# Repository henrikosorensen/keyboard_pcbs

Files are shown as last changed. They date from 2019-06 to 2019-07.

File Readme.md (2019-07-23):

GPLV2 licensed replacement keyboard PCBs.

# Omnikey 
Requires an Teensy++ 2.0 controller. - Firmware at https://github.com/qmk/qmk_firmware/tree/master/keyboards/omnikeyish

## Changelog

#### 1.3
* Nav cluster to Numpad cluster distance was off by 1/32 of an inch (0.7935mm). Meassurement confirmed on two original Omnikey PCBs and Plus rev3 plate. Not quite sure how I managed to assemble the first board.
* Rev1/3 Mounting holes got jumbled up in Schematic Reorganisation. Fixed now.

#### 1.1
* Teensy++ 2.0 uses pin D6 for an LED, so that interfers with the ROW5 assignment used on 1.0 boards. Moved ROW5 to pin E6

# AT101
Requires an Teensy 2.0 controller 

## Changelog

### 1.1
* Nav and numeric cluster distances to the alpha block were off by 1/32 inch.
* Big Arse Enter footprint updated, so stabiliser hole is large enough.

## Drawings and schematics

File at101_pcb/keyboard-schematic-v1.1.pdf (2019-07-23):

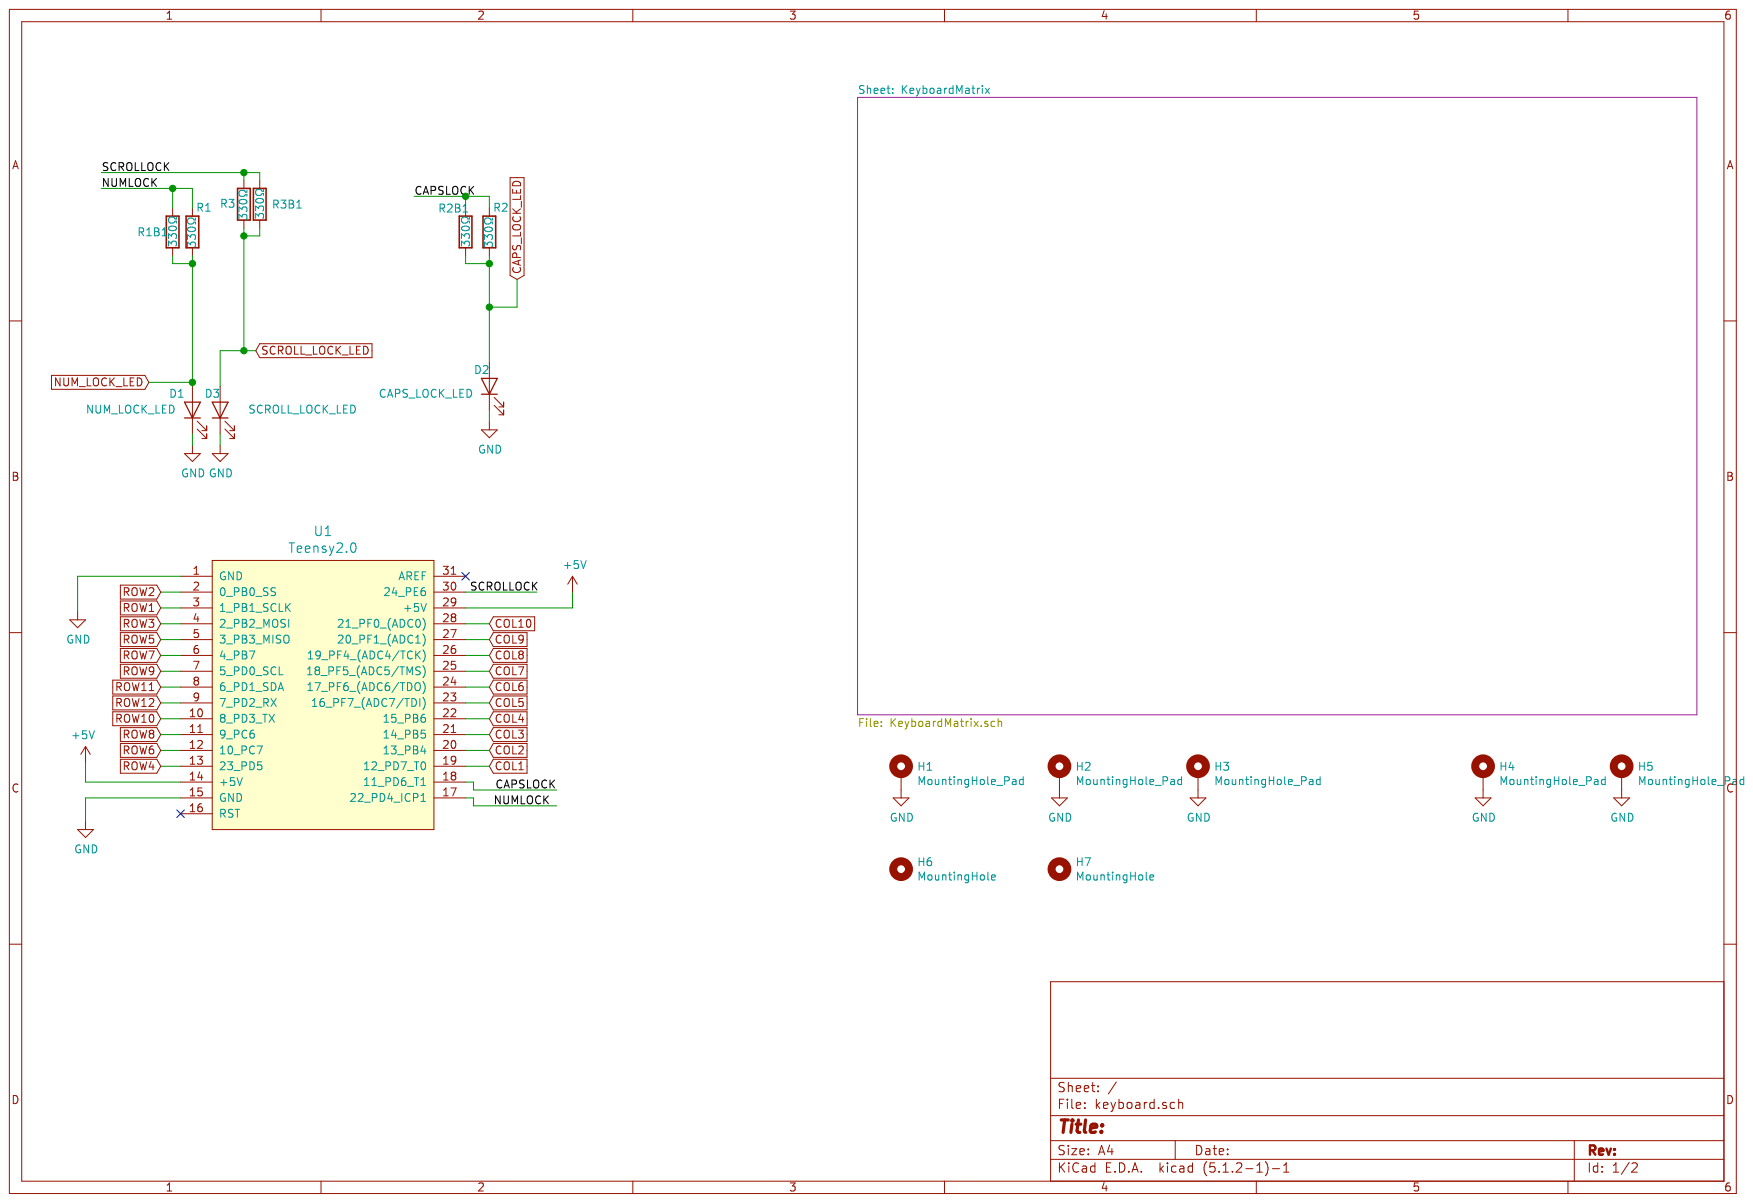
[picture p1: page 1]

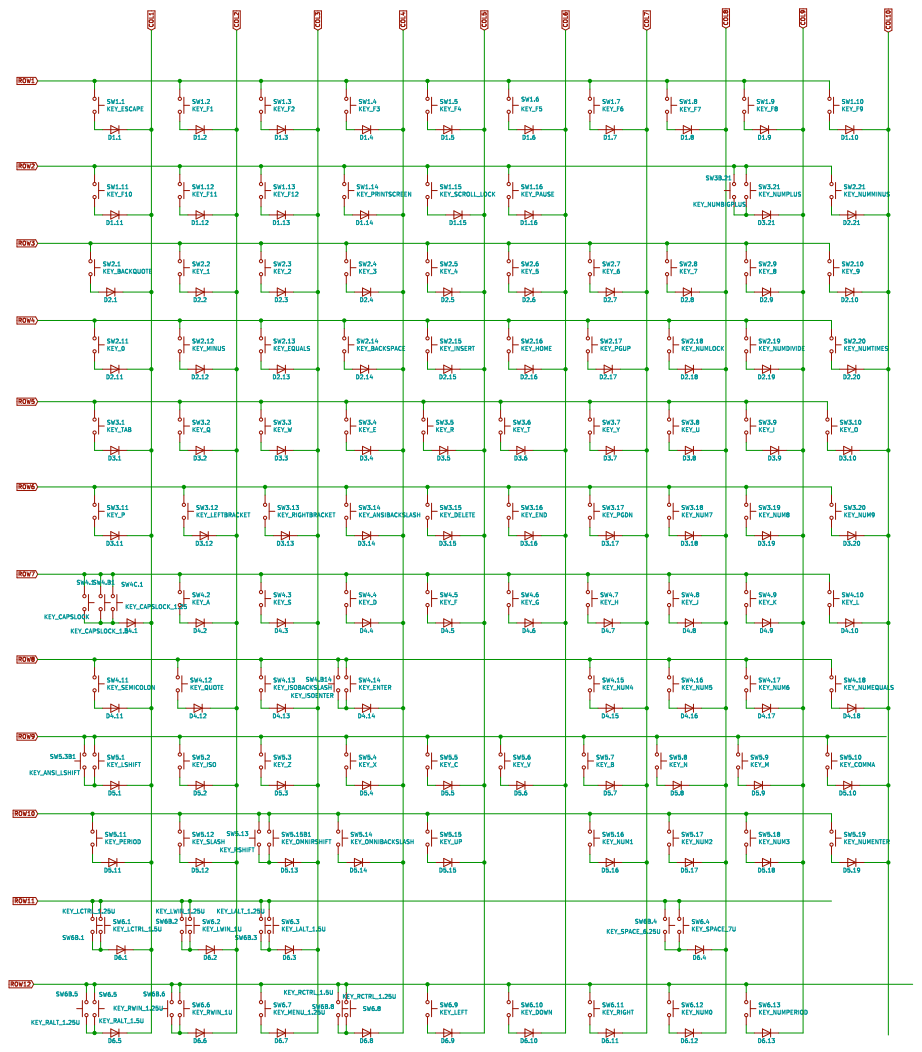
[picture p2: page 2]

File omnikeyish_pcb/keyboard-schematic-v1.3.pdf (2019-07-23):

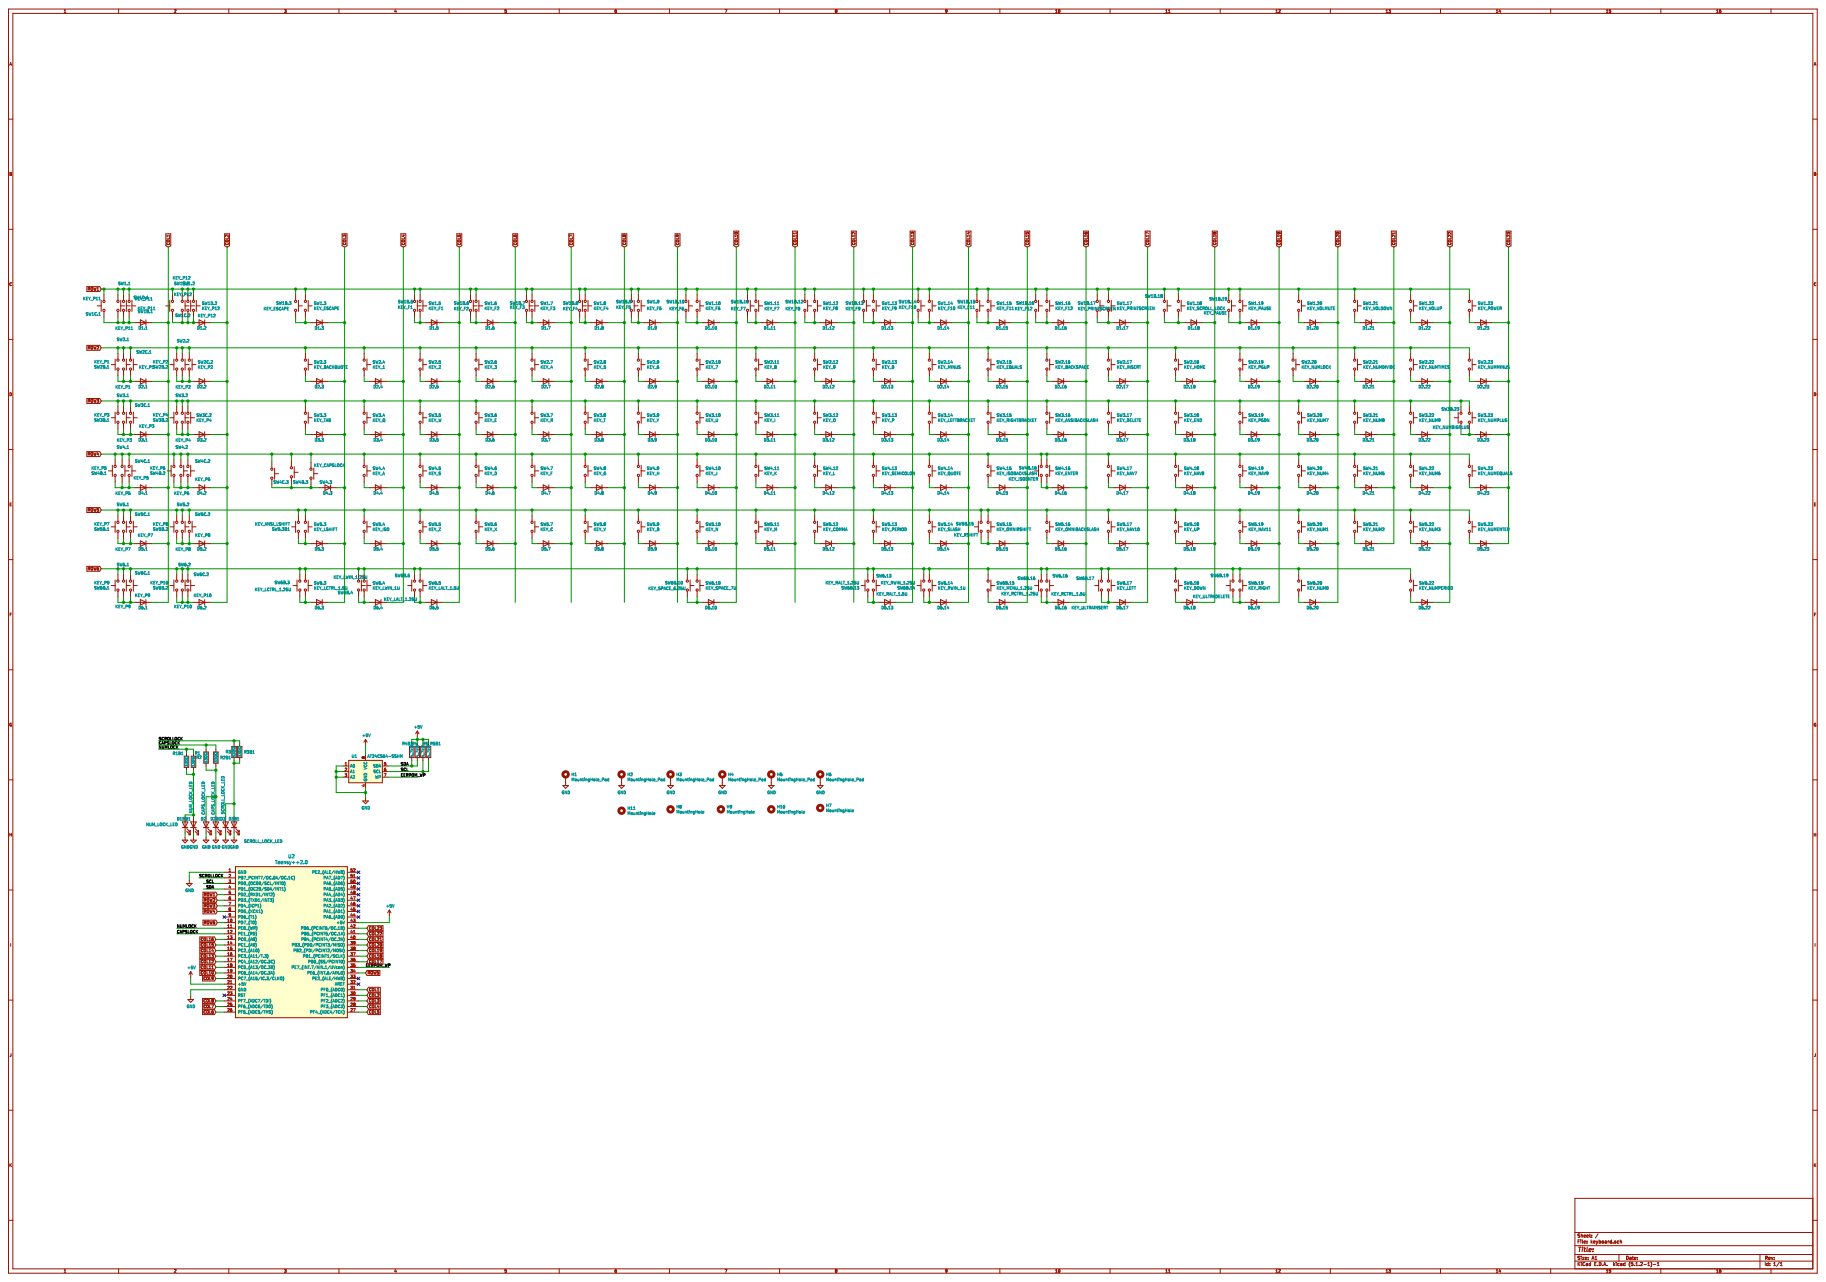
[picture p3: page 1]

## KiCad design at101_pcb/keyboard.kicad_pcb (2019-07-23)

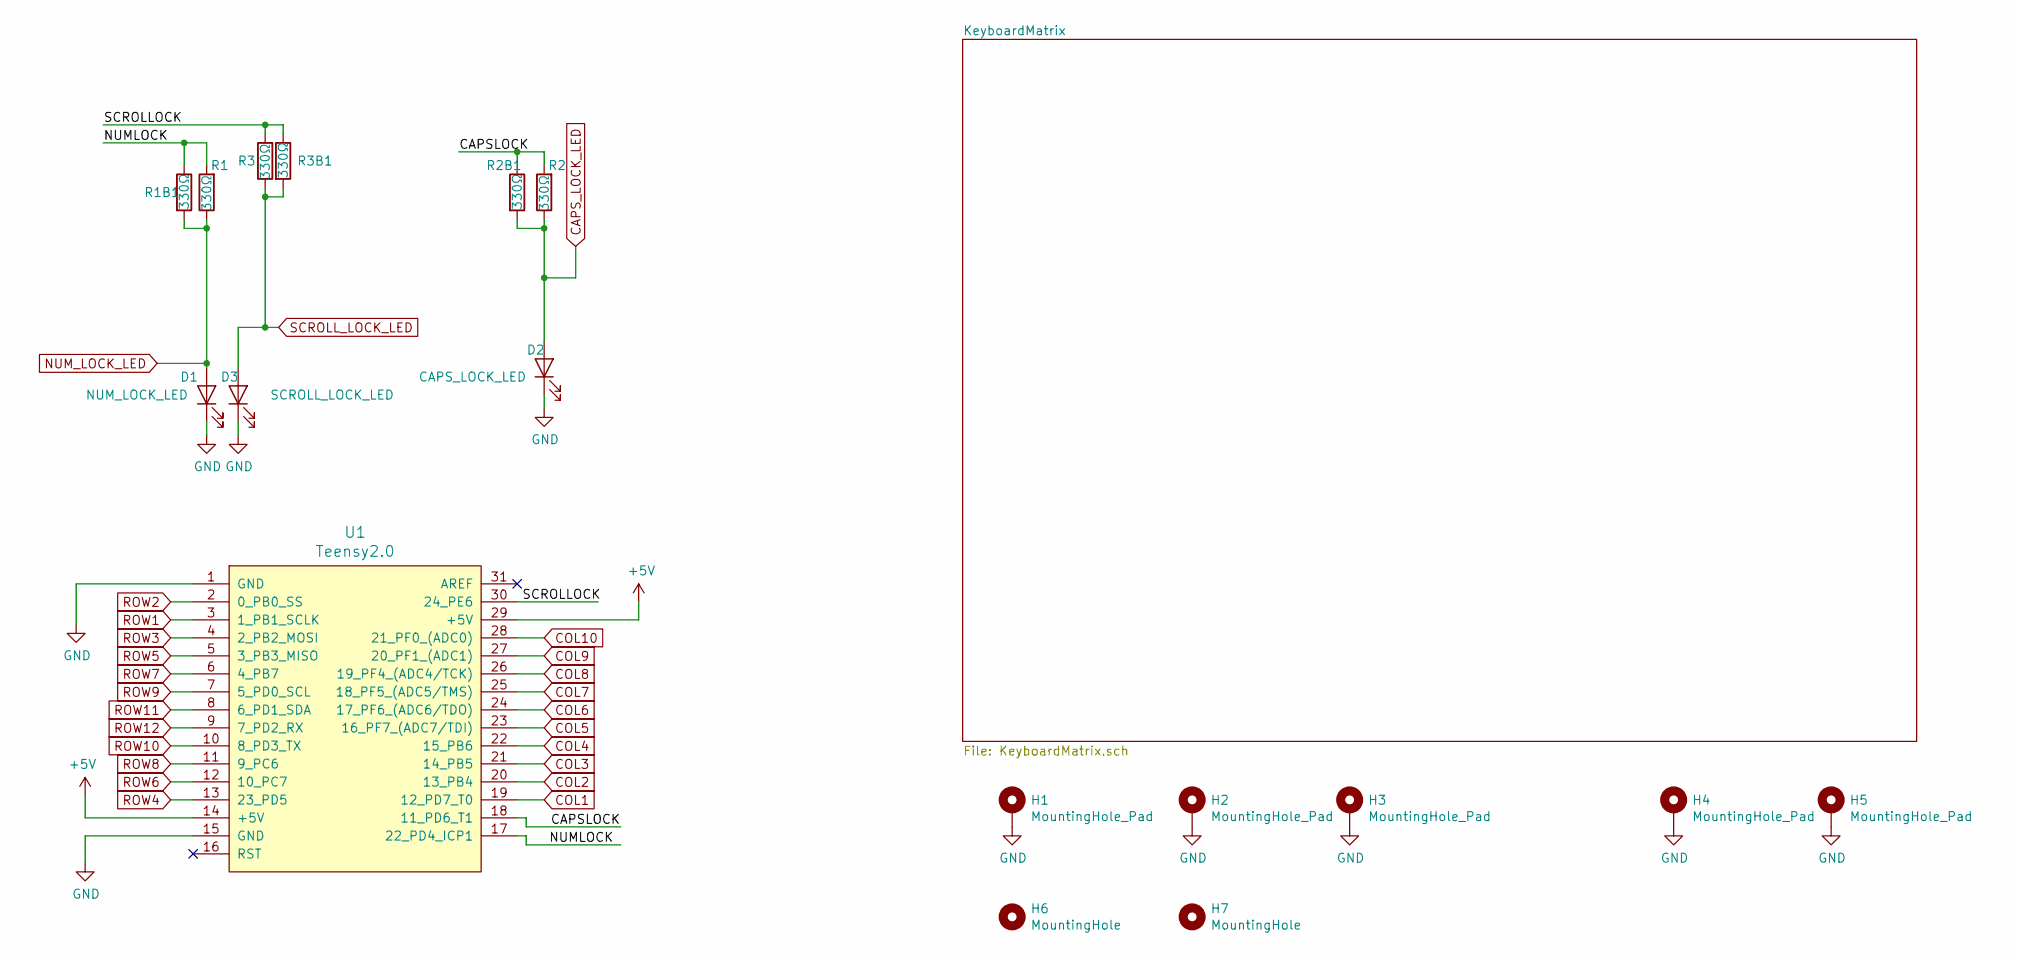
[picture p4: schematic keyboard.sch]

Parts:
D1: NUM_LOCK_LED; LED_Rectangular_W5.0mm_H2.0mm
D2: CAPS_LOCK_LED; LED_Rectangular_W5.0mm_H2.0mm
D3: SCROLL_LOCK_LED; LED_Rectangular_W5.0mm_H2.0mm
H1, H2, H3, H4, H5: MountingHole_Pad; MountingHole_3.7mm_Pad
H6, H7: MountingHole; MountingHole_11mm
R1, R2, R3: 330Ω; R_Axial_DIN0207_L6.3mm_D2.5mm_P10.16mm_Horizontal
R1B1, R2B1, R3B1: 330Ω; R_1206_3216Metric_Pad1.42x1.75mm_HandSolder
U1: Teensy2.0

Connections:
+5V: U1.14 (+5V), U1.29 (+5V)
/CAPSLOCK: R2.2, R2B1.1, U1.18 (11_PD6_T1)
/NUMLOCK: R1.2, R1B1.1, U1.17 (22_PD4_ICP1)
/SCROLLOCK: R3.2, R3B1.1, U1.30 (24_PE6)
CAPS_LOCK_LED: D2.2 (A), R2.1, R2B1.2
COL1: U1.19 (12_PD7_T0); also elsewhere on the board
COL2: U1.20 (13_PB4); also elsewhere on the board
COL3: U1.21 (14_PB5); also elsewhere on the board
COL4: U1.22 (15_PB6); also elsewhere on the board
COL5: U1.23 (16_PF7_(ADC7/TDI)); also elsewhere on the board
COL6: U1.24 (17_PF6_(ADC6/TDO)); also elsewhere on the board
COL7: U1.25 (18_PF5_(ADC5/TMS)); also elsewhere on the board
COL8: U1.26 (19_PF4_(ADC4/TCK)); also elsewhere on the board
COL9: U1.27 (20_PF1_(ADC1)); also elsewhere on the board
COL10: U1.28 (21_PF0_(ADC0)); also elsewhere on the board
GND: D1.1 (K), D2.1 (K), D3.1 (K), H1.1, H2.1, H3.1, H4.1, H5.1, U1.1 (GND), U1.15 (GND)
NUM_LOCK_LED: D1.2 (A), R1.1, R1B1.2
ROW1: U1.3 (1_PB1_SCLK); also elsewhere on the board
ROW2: U1.2 (0_PB0_SS); also elsewhere on the board
ROW3: U1.4 (2_PB2_MOSI); also elsewhere on the board
ROW4: U1.13 (23_PD5); also elsewhere on the board
ROW5: U1.5 (3_PB3_MISO); also elsewhere on the board
ROW6: U1.12 (10_PC7); also elsewhere on the board
ROW7: U1.6 (4_PB7); also elsewhere on the board
ROW8: U1.11 (9_PC6); also elsewhere on the board
ROW9: U1.7 (5_PD0_SCL); also elsewhere on the board
ROW10: U1.10 (8_PD3_TX); also elsewhere on the board
ROW11: U1.8 (6_PD1_SDA); also elsewhere on the board
ROW12: U1.9 (7_PD2_RX); also elsewhere on the board
SCROLL_LOCK_LED: D3.2 (A), R3.1, R3B1.2

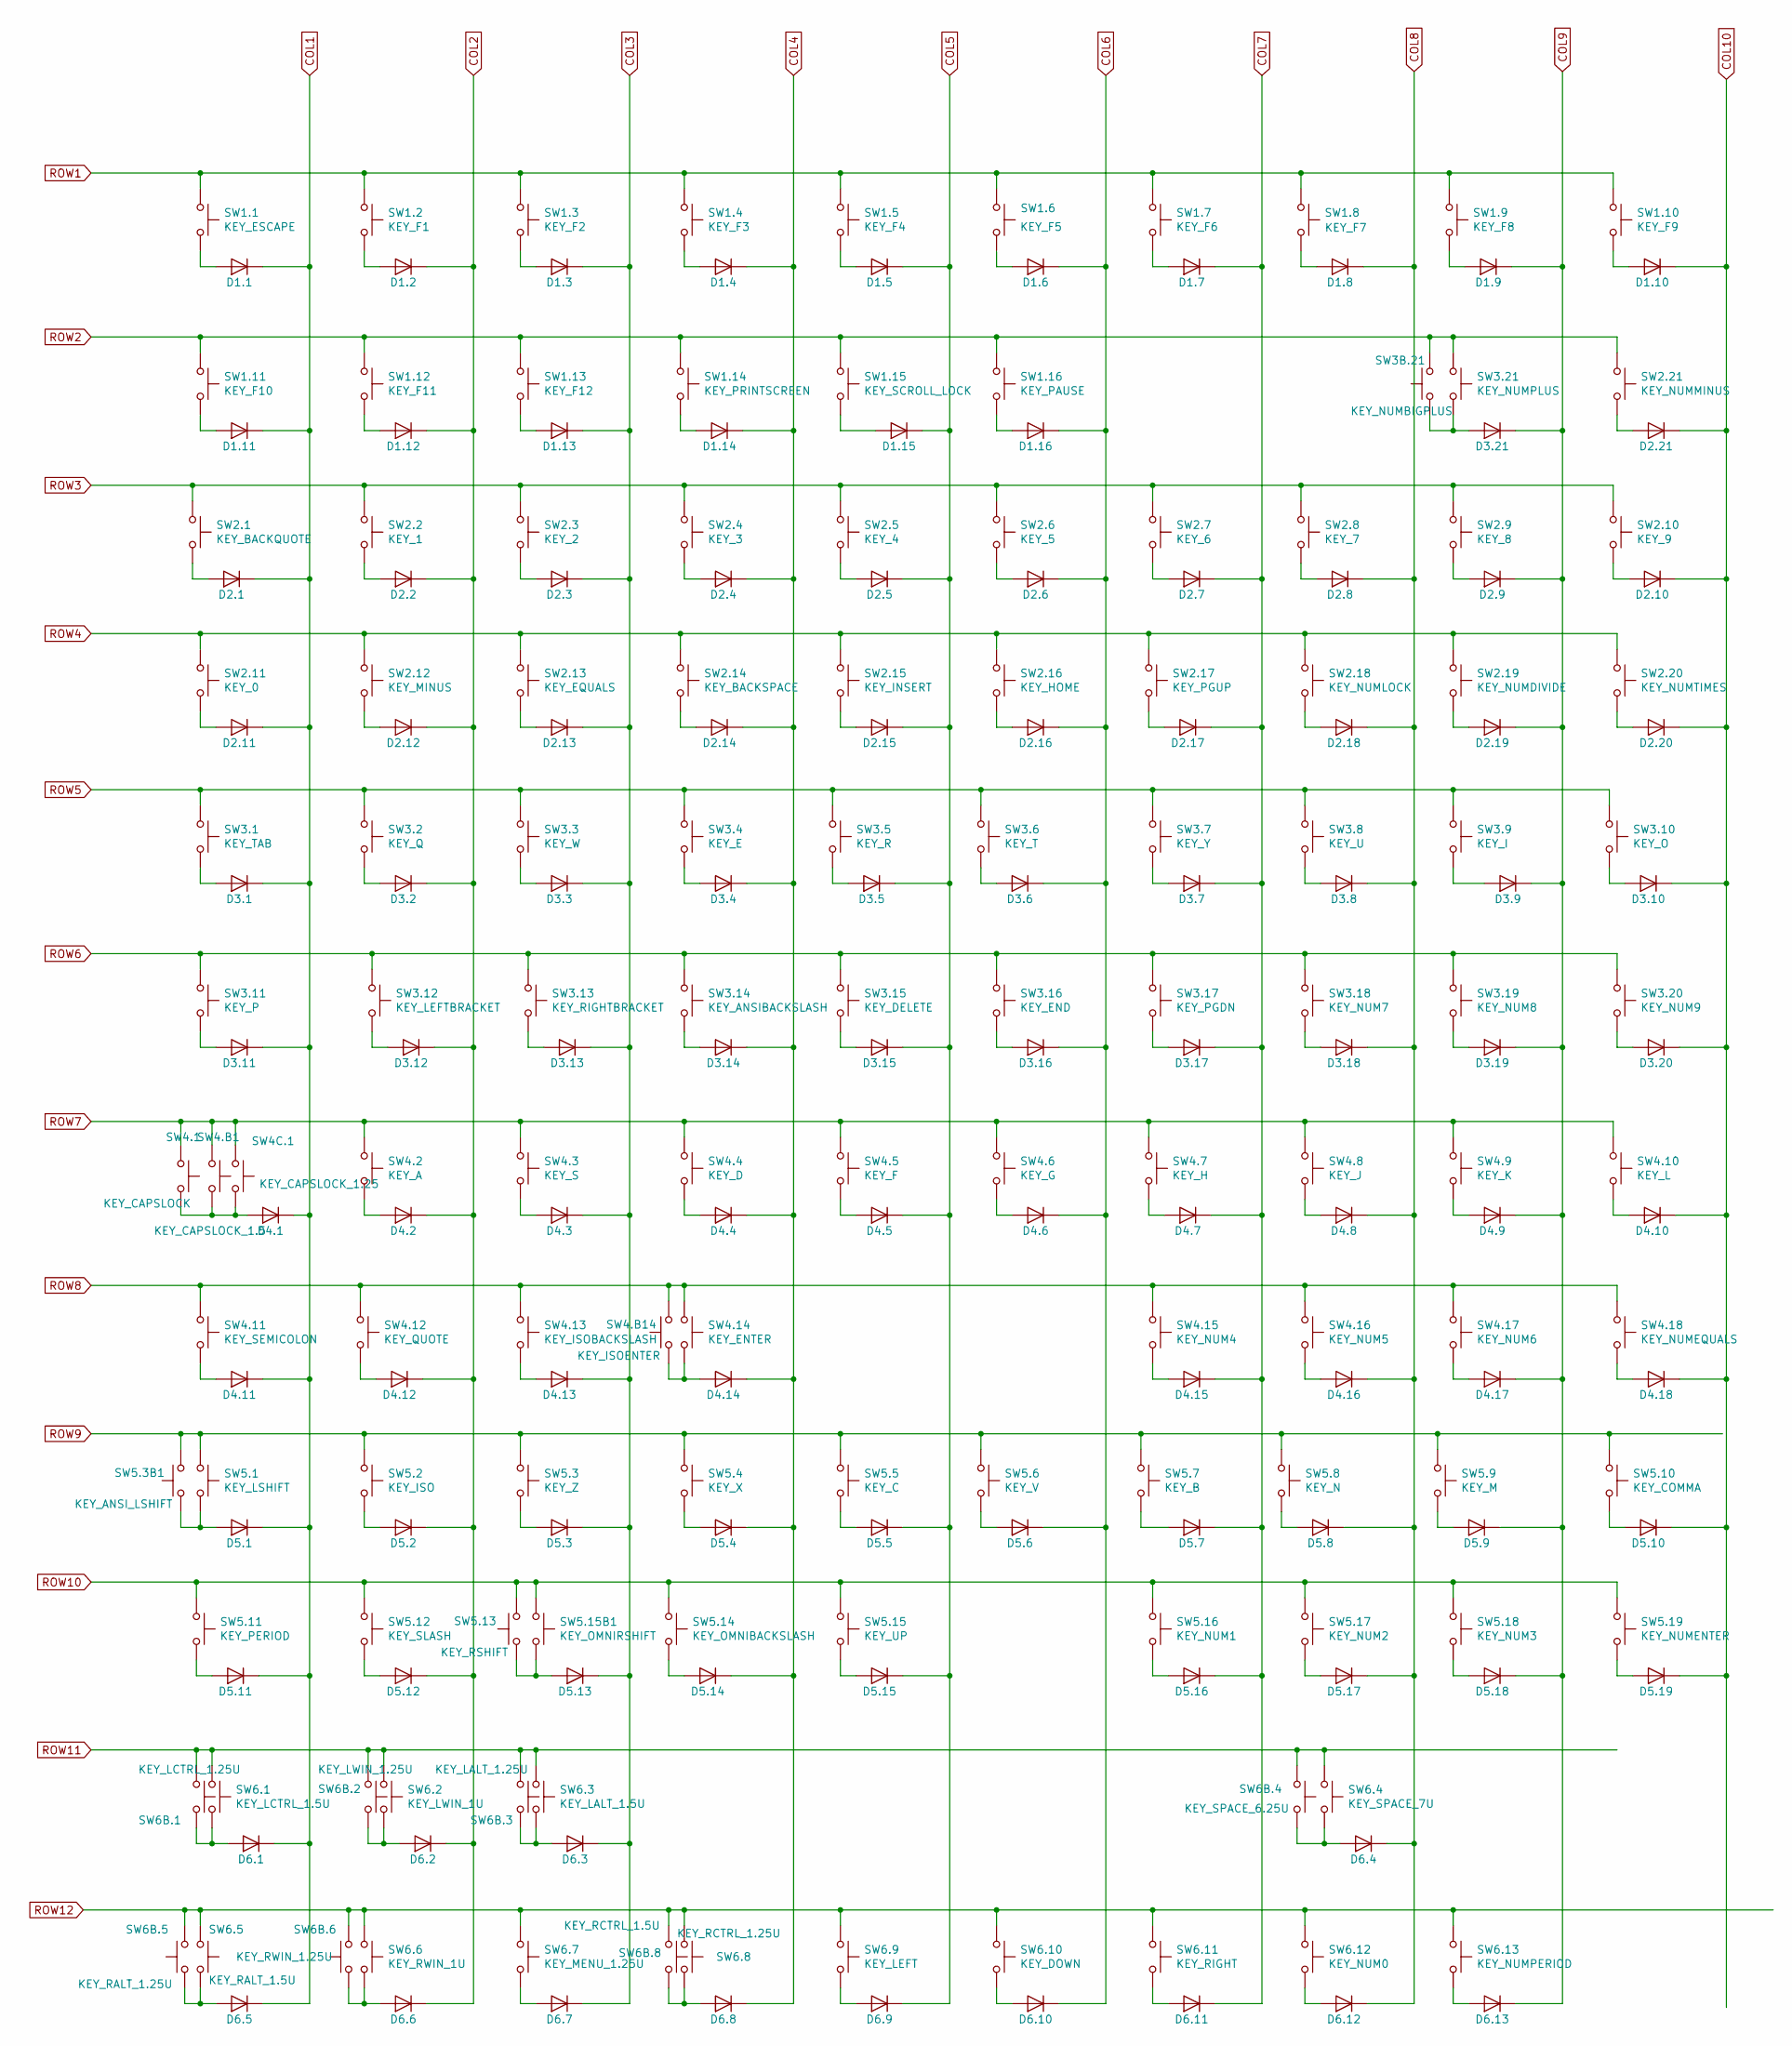
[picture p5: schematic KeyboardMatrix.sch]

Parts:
D1.1, D1.2, D1.3, D1.4, D1.5, D1.6, D1.7, D1.8, D1.9, D1.10, D1.11, D1.12, D1.13, D1.14, D1.15, D1.16, D2.1, D2.2, D2.3, D2.4, D2.5, D2.6, D2.7, D2.8, D2.9, D2.10, D2.11, D2.12, D2.13, D2.14, D2.15, D2.16, D2.17, D2.18, D2.19, D2.20, D2.21, D3.1, D3.2, D3.3, D3.4, D3.5, D3.6, D3.7, D3.8, D3.9, D3.10, D3.11, D3.12, D3.13, D3.14, D3.15, D3.16, D3.17, D3.18, D3.19, D3.20, D3.21, D4.1, D4.2, D4.3, D4.4, D4.5, D4.6, D4.7, D4.8, D4.9, D4.10, D4.11, D4.12, D4.13, D4.14, D4.15, D4.16, D4.17, D4.18, D5.1, D5.2, D5.3, D5.4, D5.5, D5.6, D5.7, D5.8, D5.9, D5.10, D5.11, D5.12, D5.13, D5.14, D5.15, D5.16, D5.17, D5.18, D5.19, D6.1, D6.2, D6.3, D6.4, D6.5, D6.6, D6.7, D6.8, D6.9, D6.10, D6.11, D6.12, D6.13: D; D_DO-35_SOD27_P7.62mm_Horizontal
SW1.1: KEY_ESCAPE; MX-1U-NoLED
SW1.2: KEY_F1; MX-1U-NoLED
SW1.3: KEY_F2; MX-1U-NoLED
SW1.4: KEY_F3; MX-1U-NoLED
SW1.5: KEY_F4; MX-1U-NoLED
SW1.6: KEY_F5; MX-1U-NoLED
SW1.7: KEY_F6; MX-1U-NoLED
SW1.8: KEY_F7; MX-1U-NoLED
SW1.9: KEY_F8; MX-1U-NoLED
SW1.10: KEY_F9; MX-1U-NoLED
SW1.11: KEY_F10; MX-1U-NoLED
SW1.12: KEY_F11; MX-1U-NoLED
SW1.13: KEY_F12; MX-1U-NoLED
SW1.14: KEY_PRINTSCREEN; MX-1U-NoLED
SW1.15: KEY_SCROLL_LOCK; MX-1U-NoLED
SW1.16: KEY_PAUSE; MX-1U-NoLED
SW2.1: KEY_BACKQUOTE; MX-1U-NoLED
SW2.2: KEY_1; MX-1U-NoLED
SW2.3: KEY_2; MX-1U-NoLED
SW2.4: KEY_3; MX-1U-NoLED
SW2.5: KEY_4; MX-1U-NoLED
SW2.6: KEY_5; MX-1U-NoLED
SW2.7: KEY_6; MX-1U-NoLED
SW2.8: KEY_7; MX-1U-NoLED
SW2.9: KEY_8; MX-1U-NoLED
SW2.10: KEY_9; MX-1U-NoLED
SW2.11: KEY_0; MX-1U-NoLED
SW2.12: KEY_MINUS; MX-1U-NoLED
SW2.13: KEY_EQUALS; MX-1U-NoLED
SW2.14: KEY_BACKSPACE; MX-2U-NoLED
SW2.15: KEY_INSERT; MX-1U-NoLED
SW2.16: KEY_HOME; MX-1U-NoLED
SW2.17: KEY_PGUP; MX-1U-NoLED
SW2.18: KEY_NUMLOCK; MX-1U-NoLED
SW2.19: KEY_NUMDIVIDE; MX-1U-NoLED
SW2.20: KEY_NUMTIMES; MX-1U-NoLED
SW2.21: KEY_NUMMINUS; MX-1U-NoLED
SW3.1: KEY_TAB; MX-1.5U-NoLED
SW3.2: KEY_Q; MX-1U-NoLED
SW3.3: KEY_W; MX-1U-NoLED
SW3.4: KEY_E; MX-1U-NoLED
SW3.5: KEY_R; MX-1U-NoLED
SW3.6: KEY_T; MX-1U-NoLED
SW3.7: KEY_Y; MX-1U-NoLED
SW3.8: KEY_U; MX-1U-NoLED
SW3.9: KEY_I; MX-1U-NoLED
SW3.10: KEY_O; MX-1U-NoLED
SW3.11: KEY_P; MX-1U-NoLED
SW3.12: KEY_LEFTBRACKET; MX-1U-NoLED
SW3.13: KEY_RIGHTBRACKET; MX-1U-NoLED
SW3.14: KEY_ANSIBACKSLASH; MX-1.5U-NoLED
SW3.15: KEY_DELETE; MX-1U-NoLED
SW3.16: KEY_END; MX-1U-NoLED
SW3.17: KEY_PGDN; MX-1U-NoLED
SW3.18: KEY_NUM7; MX-1U-NoLED
SW3.19: KEY_NUM8; MX-1U-NoLED
SW3.20: KEY_NUM9; MX-1U-NoLED
SW3.21: KEY_NUMPLUS; MX-1U-NoLED
SW3B.21: KEY_NUMBIGPLUS; MX-2U-NoLED
SW4.1: KEY_CAPSLOCK; MX-1.75U-NoLED
SW4.2: KEY_A; MX-1U-NoLED
SW4.3: KEY_S; MX-1U-NoLED
SW4.4: KEY_D; MX-1U-NoLED
SW4.5: KEY_F; MX-1U-NoLED
SW4.6: KEY_G; MX-1U-NoLED
SW4.7: KEY_H; MX-1U-NoLED
SW4.8: KEY_J; MX-1U-NoLED
SW4.9: KEY_K; MX-1U-NoLED
SW4.10: KEY_L; MX-1U-NoLED
SW4.11: KEY_SEMICOLON; MX-1U-NoLED
SW4.12: KEY_QUOTE; MX-1U-NoLED
SW4.13: KEY_ISOBACKSLASH; MX-1U-NoLED
SW4.14: KEY_ENTER; MX-Big-Ass-Enter-NoLED
SW4.15: KEY_NUM4; MX-1U-NoLED
SW4.16: KEY_NUM5; MX-1U-NoLED
SW4.17: KEY_NUM6; MX-1U-NoLED
SW4.18: KEY_NUMEQUALS; MX-1U-NoLED
SW4.B1: KEY_CAPSLOCK_1.5; MX-1.5U-NoLED
SW4.B14: KEY_ISOENTER; MX-ISO-ReversedStabilizers-NoLED
SW4C.1: KEY_CAPSLOCK_1.25; MX-1.25U-NoLED
SW5.1: KEY_LSHIFT; MX-1.25U-NoLED
SW5.2: KEY_ISO; MX-1U-NoLED
SW5.3: KEY_Z; MX-1U-NoLED
SW5.3B1: KEY_ANSI_LSHIFT; MX-2.25U-NoLED
SW5.4: KEY_X; MX-1U-NoLED
SW5.5: KEY_C; MX-1U-NoLED
SW5.6: KEY_V; MX-1U-NoLED
SW5.7: KEY_B; MX-1U-NoLED
SW5.8: KEY_N; MX-1U-NoLED
SW5.9: KEY_M; MX-1U-NoLED
SW5.10: KEY_COMMA; MX-1U-NoLED
SW5.11: KEY_PERIOD; MX-1U-NoLED
SW5.12: KEY_SLASH; MX-1U-NoLED
SW5.13: KEY_RSHIFT; MX-2.75U-NoLED
SW5.14: KEY_OMNIBACKSLASH; MX-1U-NoLED
SW5.15: KEY_UP; MX-1U-NoLED
SW5.15B1: KEY_OMNIRSHIFT; MX-1.75U-NoLED
SW5.16: KEY_NUM1; MX-1U-NoLED
SW5.17: KEY_NUM2; MX-1U-NoLED
SW5.18: KEY_NUM3; MX-1U-NoLED
SW5.19: KEY_NUMENTER; MX-2U-NoLED
SW6.1: KEY_LCTRL_1.5U; MX-1.5U-NoLED
SW6.2: KEY_LWIN_1U; MX-1U-NoLED
SW6.3: KEY_LALT_1.5U; MX-1.5U-NoLED
SW6.4: KEY_SPACE_7U; MX-7U-ReversedStabilizers-NoLED
SW6.5: KEY_RALT_1.5U; MX-1.5U-NoLED
SW6.6: KEY_RWIN_1U; MX-1U-NoLED
SW6.7: KEY_MENU_1.25U; MX-1.25U-NoLED
SW6.8: KEY_RCTRL_1.5U; MX-1.5U-NoLED
SW6.9: KEY_LEFT; MX-1U-NoLED
SW6.10: KEY_DOWN; MX-1U-NoLED
SW6.11: KEY_RIGHT; MX-1U-NoLED
SW6.12: KEY_NUM0; MX-2U-ReversedStabilizers-NoLED
SW6.13: KEY_NUMPERIOD; MX-1U-NoLED
SW6B.1: KEY_LCTRL_1.25U; MX-1.25U-NoLED
SW6B.2: KEY_LWIN_1.25U; MX-1.25U-NoLED
SW6B.3: KEY_LALT_1.25U; MX-1.25U-NoLED
SW6B.4: KEY_SPACE_6.25U; MX-6.25U-ReversedStabilizers-NoLED
SW6B.5: KEY_RALT_1.25U; MX-1.25U-NoLED
SW6B.6: KEY_RWIN_1.25U; MX-1.25U-NoLED
SW6B.8: KEY_RCTRL_1.25U; MX-1.25U-NoLED

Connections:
COL1: D1.1.1 (K), D1.11.1 (K), D2.1.1 (K), D2.11.1 (K), D3.1.1 (K), D3.11.1 (K), D4.1.1 (K), D4.11.1 (K), D5.1.1 (K), D5.11.1 (K), D6.1.1 (K), D6.5.1 (K); also elsewhere on the board
COL2: D1.2.1 (K), D1.12.1 (K), D2.2.1 (K), D2.12.1 (K), D3.2.1 (K), D3.12.1 (K), D4.2.1 (K), D4.12.1 (K), D5.2.1 (K), D5.12.1 (K), D6.2.1 (K), D6.6.1 (K); also elsewhere on the board
COL3: D1.3.1 (K), D1.13.1 (K), D2.3.1 (K), D2.13.1 (K), D3.3.1 (K), D3.13.1 (K), D4.3.1 (K), D4.13.1 (K), D5.3.1 (K), D5.13.1 (K), D6.3.1 (K), D6.7.1 (K); also elsewhere on the board
COL4: D1.4.1 (K), D1.14.1 (K), D2.4.1 (K), D2.14.1 (K), D3.4.1 (K), D3.14.1 (K), D4.4.1 (K), D4.14.1 (K), D5.4.1 (K), D5.14.1 (K), D6.8.1 (K); also elsewhere on the board
COL5: D1.5.1 (K), D1.15.1 (K), D2.5.1 (K), D2.15.1 (K), D3.5.1 (K), D3.15.1 (K), D4.5.1 (K), D5.5.1 (K), D5.15.1 (K), D6.9.1 (K); also elsewhere on the board
COL6: D1.6.1 (K), D1.16.1 (K), D2.6.1 (K), D2.16.1 (K), D3.6.1 (K), D3.16.1 (K), D4.6.1 (K), D5.6.1 (K), D6.10.1 (K); also elsewhere on the board
COL7: D1.7.1 (K), D2.7.1 (K), D2.17.1 (K), D3.7.1 (K), D3.17.1 (K), D4.7.1 (K), D4.15.1 (K), D5.7.1 (K), D5.16.1 (K), D6.11.1 (K); also elsewhere on the board
COL8: D1.8.1 (K), D2.8.1 (K), D2.18.1 (K), D3.8.1 (K), D3.18.1 (K), D4.8.1 (K), D4.16.1 (K), D5.8.1 (K), D5.17.1 (K), D6.4.1 (K), D6.12.1 (K); also elsewhere on the board
COL9: D1.9.1 (K), D2.9.1 (K), D2.19.1 (K), D3.9.1 (K), D3.19.1 (K), D3.21.1 (K), D4.9.1 (K), D4.17.1 (K), D5.9.1 (K), D5.18.1 (K), D6.13.1 (K); also elsewhere on the board
COL10: D1.10.1 (K), D2.10.1 (K), D2.20.1 (K), D2.21.1 (K), D3.10.1 (K), D3.20.1 (K), D4.10.1 (K), D4.18.1 (K), D5.10.1 (K), D5.19.1 (K); also elsewhere on the board
unnamed: D1.1.2 (A), SW1.1.2
unnamed: D1.2.2 (A), SW1.2.2
unnamed: D1.3.2 (A), SW1.3.2
unnamed: D1.4.2 (A), SW1.4.2
unnamed: D1.5.2 (A), SW1.5.2
unnamed: D1.6.2 (A), SW1.6.2
unnamed: D1.7.2 (A), SW1.7.2
unnamed: D1.8.2 (A), SW1.8.2
unnamed: D1.9.2 (A), SW1.9.2
unnamed: D1.10.2 (A), SW1.10.2
unnamed: D1.11.2 (A), SW1.11.2
unnamed: D1.12.2 (A), SW1.12.2
unnamed: D1.13.2 (A), SW1.13.2
unnamed: D1.14.2 (A), SW1.14.2
unnamed: D1.15.2 (A), SW1.15.2
unnamed: D1.16.2 (A), SW1.16.2
unnamed: D2.1.2 (A), SW2.1.2
unnamed: D2.2.2 (A), SW2.2.2
unnamed: D2.3.2 (A), SW2.3.2
unnamed: D2.4.2 (A), SW2.4.2
unnamed: D2.5.2 (A), SW2.5.2
unnamed: D2.6.2 (A), SW2.6.2
unnamed: D2.7.2 (A), SW2.7.2
unnamed: D2.8.2 (A), SW2.8.2
unnamed: D2.9.2 (A), SW2.9.2
unnamed: D2.10.2 (A), SW2.10.2
unnamed: D2.11.2 (A), SW2.11.2
unnamed: D2.12.2 (A), SW2.12.2
unnamed: D2.13.2 (A), SW2.13.2
unnamed: D2.14.2 (A), SW2.14.2
unnamed: D2.15.2 (A), SW2.15.2
unnamed: D2.16.2 (A), SW2.16.2
unnamed: D2.17.2 (A), SW2.17.2
unnamed: D2.18.2 (A), SW2.18.2
unnamed: D2.19.2 (A), SW2.19.2
unnamed: D2.20.2 (A), SW2.20.2
unnamed: D2.21.2 (A), SW2.21.2
unnamed: D3.1.2 (A), SW3.1.2
unnamed: D3.2.2 (A), SW3.2.2
unnamed: D3.3.2 (A), SW3.3.2
unnamed: D3.4.2 (A), SW3.4.2
unnamed: D3.5.2 (A), SW3.5.2
unnamed: D3.6.2 (A), SW3.6.2
unnamed: D3.7.2 (A), SW3.7.2
unnamed: D3.8.2 (A), SW3.8.2
unnamed: D3.9.2 (A), SW3.9.2
unnamed: D3.10.2 (A), SW3.10.2
unnamed: D3.11.2 (A), SW3.11.2
unnamed: D3.12.2 (A), SW3.12.2
unnamed: D3.13.2 (A), SW3.13.2
unnamed: D3.14.2 (A), SW3.14.2
unnamed: D3.15.2 (A), SW3.15.2
unnamed: D3.16.2 (A), SW3.16.2
unnamed: D3.17.2 (A), SW3.17.2
unnamed: D3.18.2 (A), SW3.18.2
unnamed: D3.19.2 (A), SW3.19.2
unnamed: D3.20.2 (A), SW3.20.2
unnamed: D3.21.2 (A), SW3.21.2, SW3B.21.1
unnamed: D4.1.2 (A), SW4.1.2, SW4.B1.2, SW4C.1.2
unnamed: D4.2.2 (A), SW4.2.2
unnamed: D4.3.2 (A), SW4.3.2
unnamed: D4.4.2 (A), SW4.4.2
unnamed: D4.5.2 (A), SW4.5.2
unnamed: D4.6.2 (A), SW4.6.2
unnamed: D4.7.2 (A), SW4.7.2
unnamed: D4.8.2 (A), SW4.8.2
unnamed: D4.9.2 (A), SW4.9.2
unnamed: D4.10.2 (A), SW4.10.2
unnamed: D4.11.2 (A), SW4.11.2
unnamed: D4.12.2 (A), SW4.12.2
unnamed: D4.13.2 (A), SW4.13.2
unnamed: D4.14.2 (A), SW4.14.2, SW4.B14.1
unnamed: D4.15.2 (A), SW4.15.2
unnamed: D4.16.2 (A), SW4.16.2
unnamed: D4.17.2 (A), SW4.17.2
unnamed: D4.18.2 (A), SW4.18.2
unnamed: D5.1.2 (A), SW5.1.2, SW5.3B1.1
unnamed: D5.2.2 (A), SW5.2.2
unnamed: D5.3.2 (A), SW5.3.2
unnamed: D5.4.2 (A), SW5.4.2
unnamed: D5.5.2 (A), SW5.5.2
unnamed: D5.6.2 (A), SW5.6.2
unnamed: D5.7.2 (A), SW5.7.2
unnamed: D5.8.2 (A), SW5.8.2
unnamed: D5.9.2 (A), SW5.9.2
unnamed: D5.10.2 (A), SW5.10.2
unnamed: D5.11.2 (A), SW5.11.2
unnamed: D5.12.2 (A), SW5.12.2
unnamed: D5.13.2 (A), SW5.13.1, SW5.15B1.2
unnamed: D5.14.2 (A), SW5.14.2
unnamed: D5.15.2 (A), SW5.15.2
unnamed: D5.16.2 (A), SW5.16.2
unnamed: D5.17.2 (A), SW5.17.2
unnamed: D5.18.2 (A), SW5.18.2
unnamed: D5.19.2 (A), SW5.19.2
unnamed: D6.1.2 (A), SW6.1.2, SW6B.1.2
unnamed: D6.2.2 (A), SW6.2.2, SW6B.2.2
unnamed: D6.3.2 (A), SW6.3.2, SW6B.3.2
unnamed: D6.4.2 (A), SW6.4.2, SW6B.4.2
unnamed: D6.5.2 (A), SW6.5.2, SW6B.5.1
unnamed: D6.6.2 (A), SW6.6.2, SW6B.6.1
unnamed: D6.7.2 (A), SW6.7.2
unnamed: D6.8.2 (A), SW6.8.2, SW6B.8.2
unnamed: D6.9.2 (A), SW6.9.2
unnamed: D6.10.2 (A), SW6.10.2
unnamed: D6.11.2 (A), SW6.11.2
unnamed: D6.12.2 (A), SW6.12.2
unnamed: D6.13.2 (A), SW6.13.2
ROW1: SW1.1.1, SW1.2.1, SW1.3.1, SW1.4.1, SW1.5.1, SW1.6.1, SW1.7.1, SW1.8.1, SW1.9.1, SW1.10.1; also elsewhere on the board
ROW2: SW1.11.1, SW1.12.1, SW1.13.1, SW1.14.1, SW1.15.1, SW1.16.1, SW2.21.1, SW3.21.1, SW3B.21.2; also elsewhere on the board
ROW3: SW2.1.1, SW2.2.1, SW2.3.1, SW2.4.1, SW2.5.1, SW2.6.1, SW2.7.1, SW2.8.1, SW2.9.1, SW2.10.1; also elsewhere on the board
ROW4: SW2.11.1, SW2.12.1, SW2.13.1, SW2.14.1, SW2.15.1, SW2.16.1, SW2.17.1, SW2.18.1, SW2.19.1, SW2.20.1; also elsewhere on the board
ROW5: SW3.1.1, SW3.2.1, SW3.3.1, SW3.4.1, SW3.5.1, SW3.6.1, SW3.7.1, SW3.8.1, SW3.9.1, SW3.10.1; also elsewhere on the board
ROW6: SW3.11.1, SW3.12.1, SW3.13.1, SW3.14.1, SW3.15.1, SW3.16.1, SW3.17.1, SW3.18.1, SW3.19.1, SW3.20.1; also elsewhere on the board
ROW7: SW4.1.1, SW4.2.1, SW4.3.1, SW4.4.1, SW4.5.1, SW4.6.1, SW4.7.1, SW4.8.1, SW4.9.1, SW4.10.1, SW4.B1.1, SW4C.1.1; also elsewhere on the board
ROW8: SW4.11.1, SW4.12.1, SW4.13.1, SW4.14.1, SW4.15.1, SW4.16.1, SW4.17.1, SW4.18.1, SW4.B14.2; also elsewhere on the board
ROW9: SW5.1.1, SW5.2.1, SW5.3.1, SW5.3B1.2, SW5.4.1, SW5.5.1, SW5.6.1, SW5.7.1, SW5.8.1, SW5.9.1, SW5.10.1; also elsewhere on the board
ROW10: SW5.11.1, SW5.12.1, SW5.13.2, SW5.14.1, SW5.15.1, SW5.15B1.1, SW5.16.1, SW5.17.1, SW5.18.1, SW5.19.1; also elsewhere on the board
ROW11: SW6.1.1, SW6.2.1, SW6.3.1, SW6.4.1, SW6B.1.1, SW6B.2.1, SW6B.3.1, SW6B.4.1; also elsewhere on the board
ROW12: SW6.5.1, SW6.6.1, SW6.7.1, SW6.8.1, SW6.9.1, SW6.10.1, SW6.11.1, SW6.12.1, SW6.13.1, SW6B.5.2, SW6B.6.2, SW6B.8.1; also elsewhere on the board

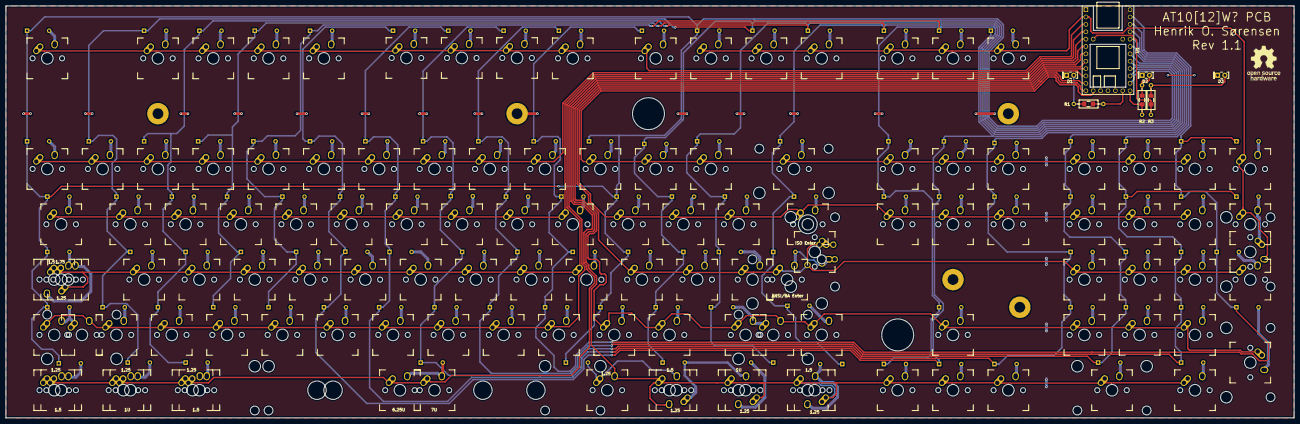
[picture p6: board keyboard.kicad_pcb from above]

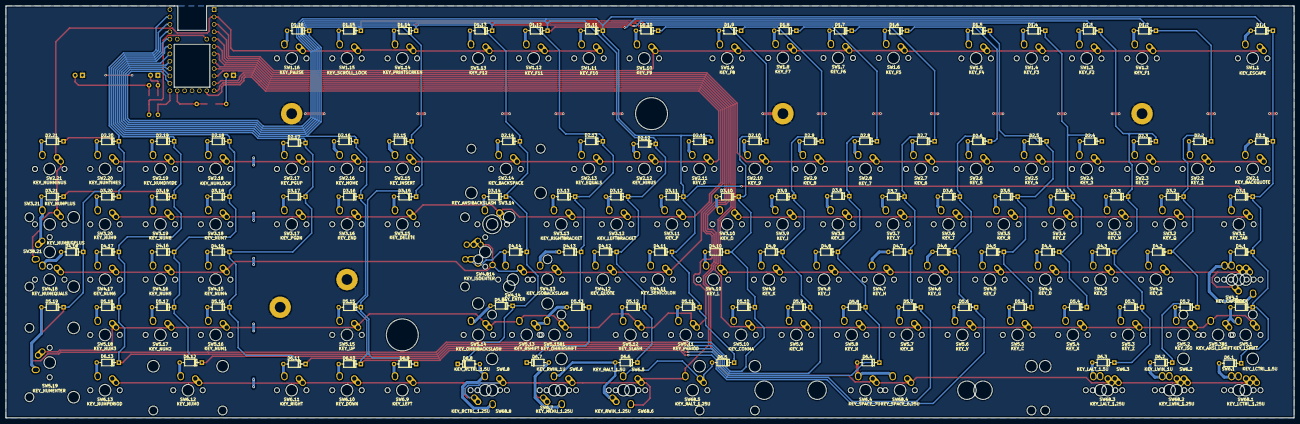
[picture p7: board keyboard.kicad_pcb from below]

Board: 2 copper layers, 443.7 x 141.9 mm, 246 parts (108 on the bottom side), 138 nets.

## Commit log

2019-06-15 Omnikeyish kicad files
    [keyboard.kicad_pcb, keyboard.sch]
2019-06-15 Add Dell AT10[12]W? PCB kicad file
    [KeyboardController.sch, KeyboardMatrix.sch, keyboard.kicad_pcb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]
2019-06-15 Add generated kicad files to .gitignore
2019-06-20 Rev 1.2: Fix brainfart matrix postion for Ultra's 1.5u insert and delete keys was wrong
    [keyboard.kicad_pcb, keyboard.sch]
2019-06-21 Tweak silk screen location of 2u numpad plus
    [keyboard.kicad_pcb]
2019-06-23 Nav cluster to Numpad cluster distance was off by 1/32 of an inch (0.7935mm).
    [keyboard.kicad_pcb]
2019-07-06 Correct AT10[12]W? switch labels
    [KeyboardMatrix.sch, keyboard.kicad_pcb, keyboard.sch]
2019-07-06 Correct nav and numeric cluster distances
    [keyboard.kicad_pcb]
2019-07-07 Update Big Arse Enter footprint.
    [keyboard.kicad_pcb]
2019-07-23 Add schematic and gerber output for ease of use by github vistors
    [keyboard.kicad_pcb]
